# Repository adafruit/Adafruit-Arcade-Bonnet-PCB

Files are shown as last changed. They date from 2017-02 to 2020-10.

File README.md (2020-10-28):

## Adafruit Arcade Bonnet PCB

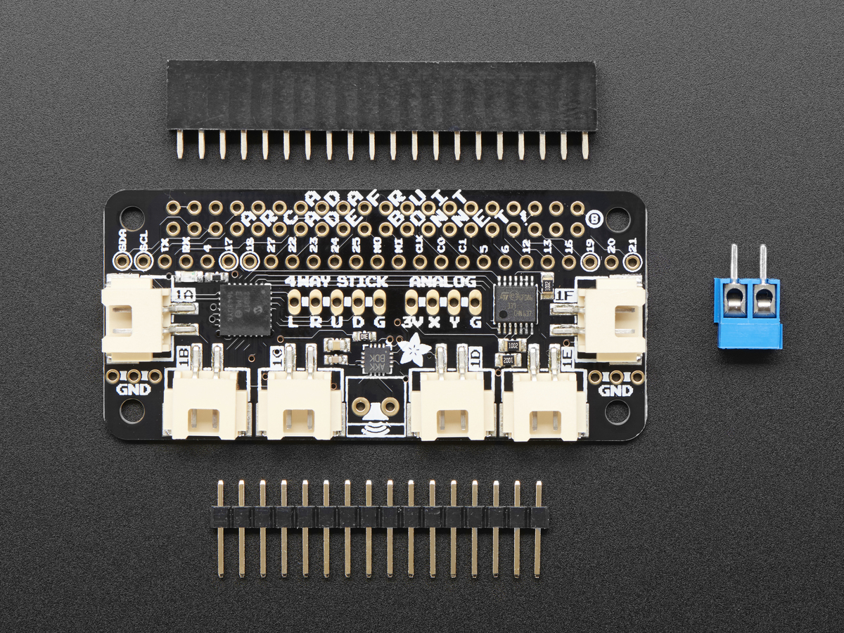
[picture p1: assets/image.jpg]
<a href="http://www.adafruit.com/products/3422"><br/>
Click here to purchase one from the Adafruit shop</a>

PCB files for the Adafruit Arcade Bonnet. Format is EagleCAD schematic and board layout
* http://www.adafruit.com/product/3422

### Description

Playing retro games is easy on a Raspberry Pi - and that pocket-sized computer is pretty good at it too! All you need is a little help to connect buttons and a joystick up and you can custom design your own arcade console, desktop or stand-up machine, even just a simple controller box. It makes for a fun weekend project that will last all year.

This Adafruit Arcade Bonnet is designed to make small emulator projects a little easier to build. Here's what you can look forward to!

* It is the same size as a Pi Zero, so for really compact builds, this is super small. You can also use it with a Pi 2, 3, B+ or any 2x20 connector Pi.
* It has JST sockets so you can plug in six arcade buttons easily using our quick connects.
* Header breakouts for use with both clicky-type switched joysticks and...
* Header breakout and converter for using analog-type joysticks or thumbsticks with potentiometers inside.
* A 3W digital speaker output that can drive 4-8 ohm speakers for when using with a TV output, audio-less HDMI display or PiTFT. Works even when the Pi doesn't have a headphone jack!
* Switches are all managed with an I2C-GPIO converter with interrupt out. The converter is very fast and frees up all the pins so you can use this Bonnet with a PiTFT or any other accessory/device that uses a lot of pins!

If you don't need an amplified speaker output, analog-joystick input or minimal pin usage, check out our plain-jane Retrogame tutorial which just plugs all the buttons and joysticks right into the Pi directly.

This item as sold as a mini-kit, with a Bonnet and headers that need to be soldered in to attach it to a Raspberry Pi! It only takes a few minutes but soldering iron and solder are required.

Note: The terminal block included with your product may be blue or black.

It also does not come with any of the extras, so you can choose which buttons/joysticks/speaker you want! Here is a list of the items you can use:

Joysticks:

* Small Arcade Joystick
* Mini Analog Joystick
* Assembled 2 Axis Joystick
* Analog Thumbstick
* 2 Axis Joystick
* PSP Analog Joystick
* PSP3000 Analog Joystick

To connect them, you may want some 20 x 12" Female jumper wires.

Speakers:

* 4 ohm 3 Watt speaker
* 8 ohm 1 Watt speaker
* Mono enclosed speaker
* Mini Metal speaker (may need to turn the volume down in Emulation station)
* Thin Plastic speaker (may need to turn the volume down in Emulation station)

Arcade Buttons:

* The JST connectors on the Bonnet mate perfectly with Arcade Button Quick-Connect Wire Pairs.
* Any of our Arcade buttons will work. You can use any switch you like, really – doesn't even need to be a button!
* The translucent 30mm ones work nicely with the quick-connects and are recommended!

Note: Raspberry Pi, arcade buttons, joysticks, speaker, display, and quick-connect wires are NOT included, and must be purchased separately.

Once you've picked out all your buttons and joysticks and stuff, check out our [Getting-started guide](https://learn.adafruit.com/adafruit-arcade-bonnet-for-raspberry-pi to help you get going!

### License

Adafruit invests time and resources providing this open source design, please support Adafruit and open-source hardware by purchasing products from [Adafruit](https://www.adafruit.com)!

Designed by Limor Fried/Ladyada for Adafruit Industries.

Creative Commons Attribution/Share-Alike, all text above must be included in any redistribution. See license.txt for additional details.

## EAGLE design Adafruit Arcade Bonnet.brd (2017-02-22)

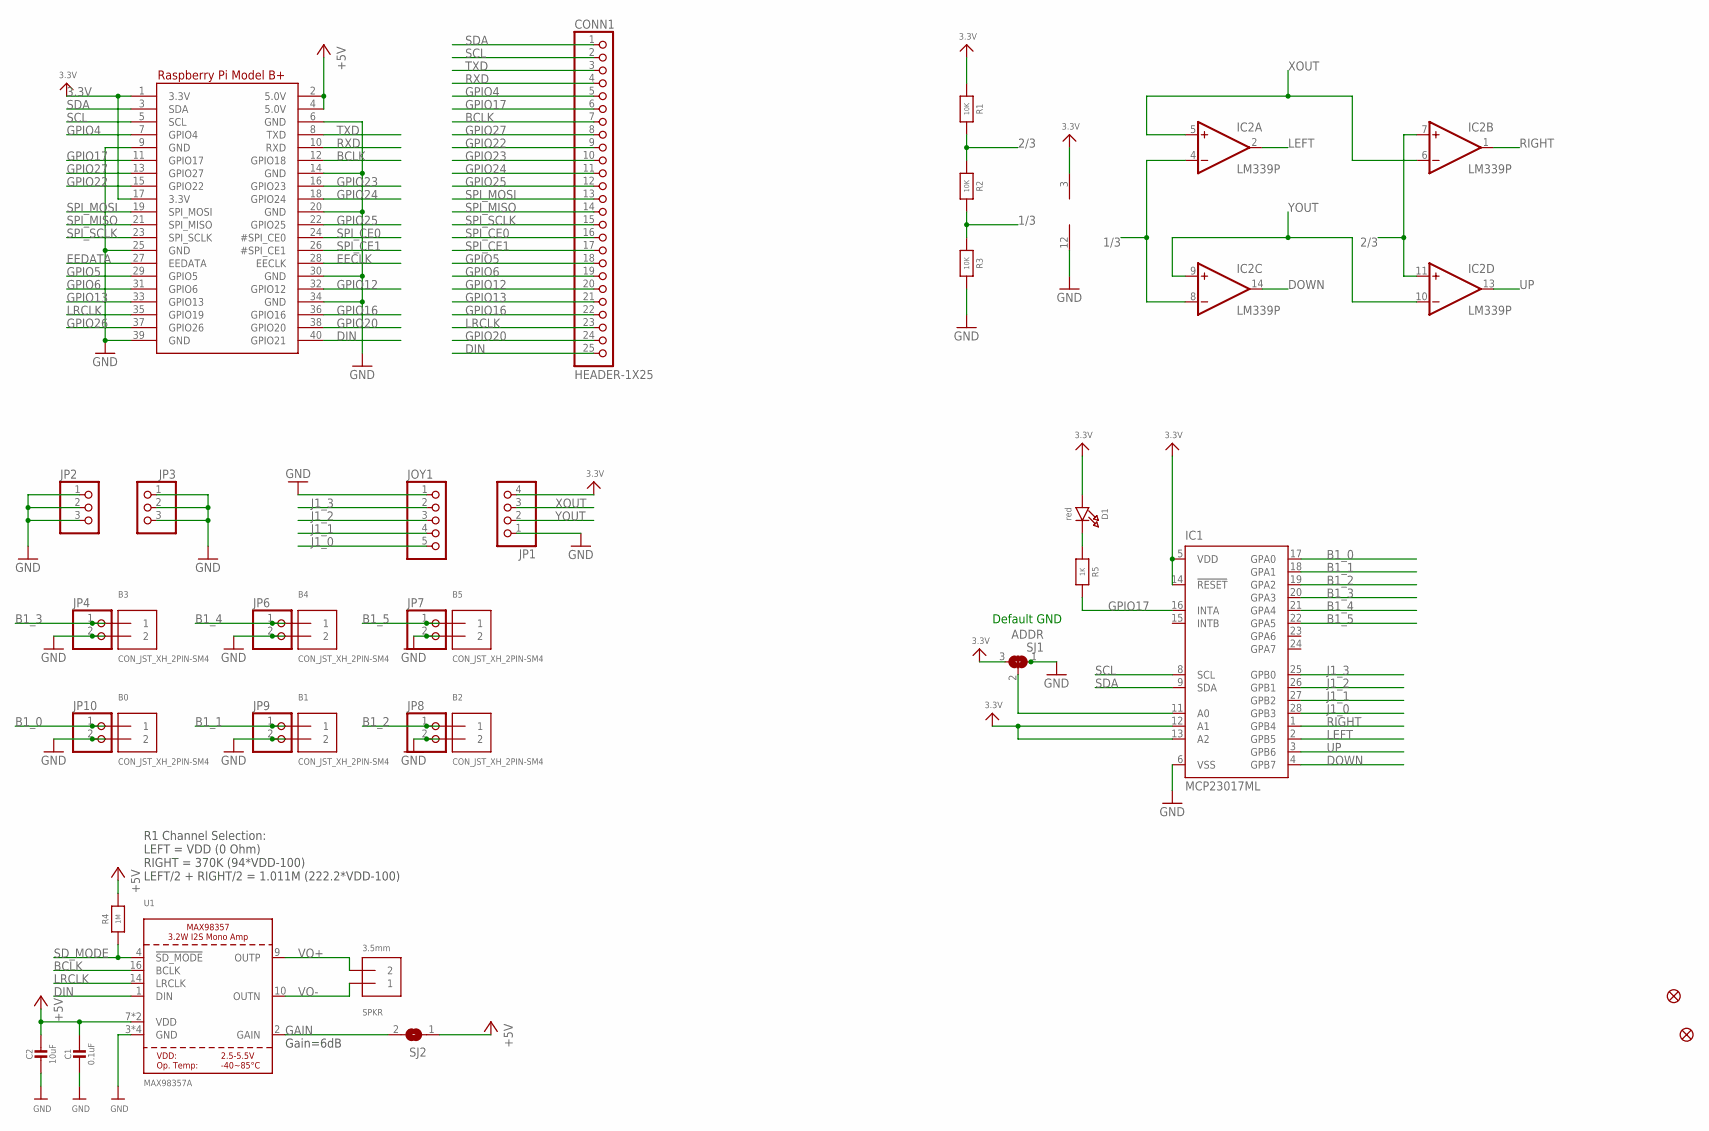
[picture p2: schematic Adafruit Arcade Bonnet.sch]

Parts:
B0, B1, B2, B3, B4, B5: CON_JST_XH_2PIN-SM4; JST-XH-2-SM4
C1: 0.1uF; 0603-NO
C2: 10uF; 0805-NO
CONN1: HEADER-1X25; 1X25_ROUND_70MIL
D1: red; CHIPLED_0805_NOOUTLINE
FID2, FID3: FIDUCIAL""; FIDUCIAL_1MM
IC1: MCP23017ML; QFN28-ML_6X6MM; MPN MCP23017-E/SS
IC2: LM339P; TSSOP14
JOY1: HEADER-1X5; 1X05_OVAL
JP1: HEADER-1X4; 1X04_OVAL
JP2, JP3: HEADER-1X3ROUND; 1X03_ROUND
JP4, JP6, JP7, JP8, JP9, JP10: HEADER-1X2; 1X02_OVAL
R1: 10K; 0805_10MGAP
R2, R3: 10K; 0805-NO
R4: 1M; 0603-NO
R5: 1K; 0603-NO
RPI1: RASPBERRYPI_BPLUS_PHAT; PI_BONNET
SJ1: ADDR; SOLDERJUMPER_2WAY_OPEN_NOPASTE
SJ2: SOLDERJUMPERCLOSED; SOLDERJUMPER_CLOSEDWIRE
SPKR: 3.5mm; TERMBLOCK_1X2-3.5MM
U1: MAX98357A; QFN16_3MM

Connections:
1/3: IC2.4 (-IN), IC2.8 (-IN), R2.2, R3.1
2/3: IC2.7 (+IN), IC2.11 (+IN), R1.2, R2.1
3.3V: D1.A, IC1.5 (VDD), IC1.12 (A1), IC1.13 (A2), IC1.14 (!RESET), IC2.3 (V+), JP1.4, R1.1, RPI1.1 (3.3V), RPI1.17 (3.3V), SJ1.3
+5V: C1.1, C2.1, R4.2, RPI1.2 (5.0V), RPI1.4 (5.0V), SJ2.1, U1.7 (VDD), U1.8 (VDD)
B1_0: B0.1, IC1.17 (GPA0), JP10.1
B1_1: B1.1, IC1.18 (GPA1), JP9.1
B1_2: B2.1, IC1.19 (GPA2), JP8.1
B1_3: B3.1, IC1.20 (GPA3), JP4.1
B1_4: B4.1, IC1.21 (GPA4), JP6.1
B1_5: B5.1, IC1.22 (GPA5), JP7.1
BCLK: CONN1.7, RPI1.12 (GPIO18), U1.16 (BCLK)
DIN: CONN1.25, RPI1.40 (GPIO21), U1.1 (DIN)
DOWN: IC1.4 (GPB7), IC2.14 (OUT)
EECLK: RPI1.28 (EECLK)
EEDATA: RPI1.27 (EEDATA)
GAIN: SJ2.2, U1.2 (GAIN)
GND: B0.2, B1.2, B2.2, B3.2, B4.2, B5.2, C1.2, C2.2, IC1.6 (VSS), IC2.12 (GND), JOY1.1, JP1.1, JP2.1, JP2.2, JP2.3, JP3.1, JP3.2, JP3.3, JP4.2, JP6.2, JP7.2, JP8.2, JP9.2, JP10.2, R3.2, RPI1.6 (GND), RPI1.9 (GND), RPI1.14 (GND), RPI1.20 (GND), RPI1.25 (GND), RPI1.30 (GND), RPI1.34 (GND), RPI1.39 (GND), SJ1.1, U1.3 (GND), U1.11 (GND), U1.15 (GND), U1.THERMAL (GND)
GPIO4: CONN1.5, RPI1.7 (GPIO4)
GPIO5: CONN1.18, RPI1.29 (GPIO5)
GPIO6: CONN1.19, RPI1.31 (GPIO6)
GPIO12: CONN1.20, RPI1.32 (GPIO12)
GPIO13: CONN1.21, RPI1.33 (GPIO13)
GPIO16: CONN1.22, RPI1.36 (GPIO16)
GPIO17: CONN1.6, IC1.16 (INTA), R5.2, RPI1.11 (GPIO17)
GPIO20: CONN1.24, RPI1.38 (GPIO20)
GPIO22: CONN1.9, RPI1.15 (GPIO22)
GPIO23: CONN1.10, RPI1.16 (GPIO23)
GPIO24: CONN1.11, RPI1.18 (GPIO24)
GPIO25: CONN1.12, RPI1.22 (GPIO25)
GPIO26: RPI1.37 (GPIO26)
GPIO27: CONN1.8, RPI1.13 (GPIO27)
J1_0: IC1.28 (GPB3), JOY1.5
J1_1: IC1.27 (GPB2), JOY1.4
J1_2: IC1.26 (GPB1), JOY1.3
J1_3: IC1.25 (GPB0), JOY1.2
LEFT: IC1.2 (GPB5), IC2.2 (OUT)
LRCLK: CONN1.23, RPI1.35 (GPIO19), U1.14 (LRCLK)
unnamed: IC1.11 (A0), SJ1.2
unnamed: D1.C, R5.1
RIGHT: IC1.1 (GPB4), IC2.1 (OUT)
RXD: CONN1.4, RPI1.10 (RXD)
SCL: CONN1.2, IC1.8 (SCL), RPI1.5 (SCL)
SDA: CONN1.1, IC1.9 (SDA), RPI1.3 (SDA)
SD_MODE: R4.1, U1.4 (!SD_MODE)
SPI_CE0: CONN1.16, RPI1.24 (#SPI_CE0)
SPI_CE1: CONN1.17, RPI1.26 (#SPI_CE1)
SPI_MISO: CONN1.14, RPI1.21 (SPI_MISO)
SPI_MOSI: CONN1.13, RPI1.19 (SPI_MOSI)
SPI_SCLK: CONN1.15, RPI1.23 (SPI_SCLK)
TXD: CONN1.3, RPI1.8 (TXD)
UP: IC1.3 (GPB6), IC2.13 (OUT)
VO+: SPKR.2, U1.9 (OUTP)
VO-: SPKR.1, U1.10 (OUTN)
XOUT: IC2.5 (+IN), IC2.6 (-IN), JP1.3
YOUT: IC2.9 (+IN), IC2.10 (-IN), JP1.2

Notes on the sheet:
R1 Channel Selection: LEFT = VDD (0 Ohm) RIGHT = 370K (94*VDD-100) LEFT/2 + RIGHT/2 = 1.011M (222.2*VDD-100)
Gain=6dB
Default GND

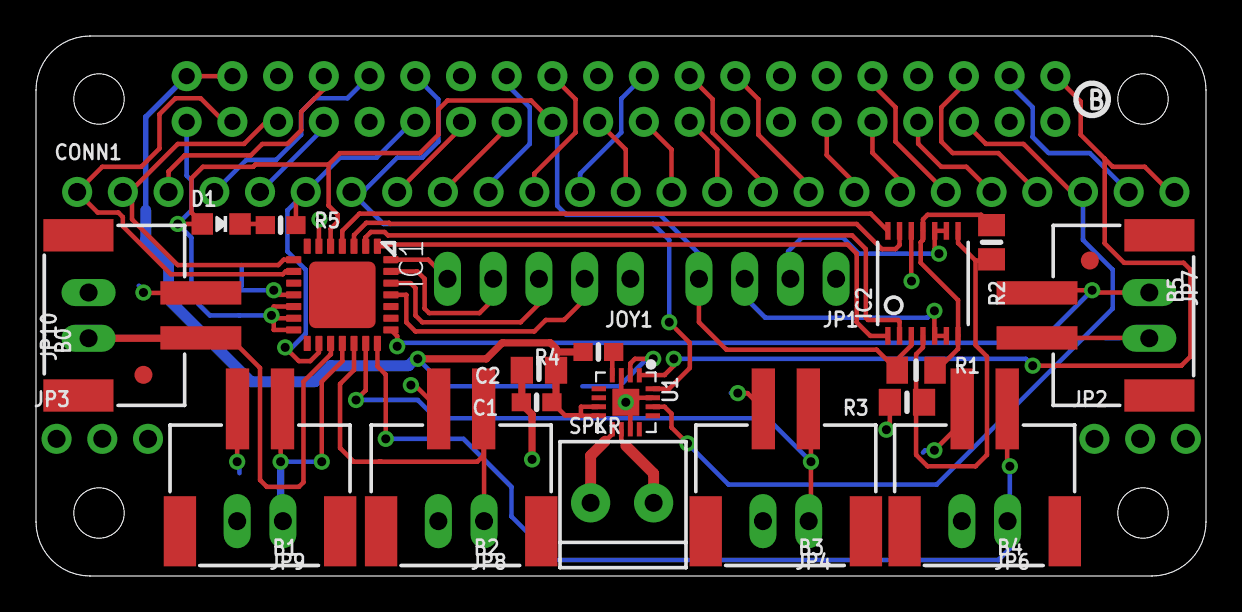
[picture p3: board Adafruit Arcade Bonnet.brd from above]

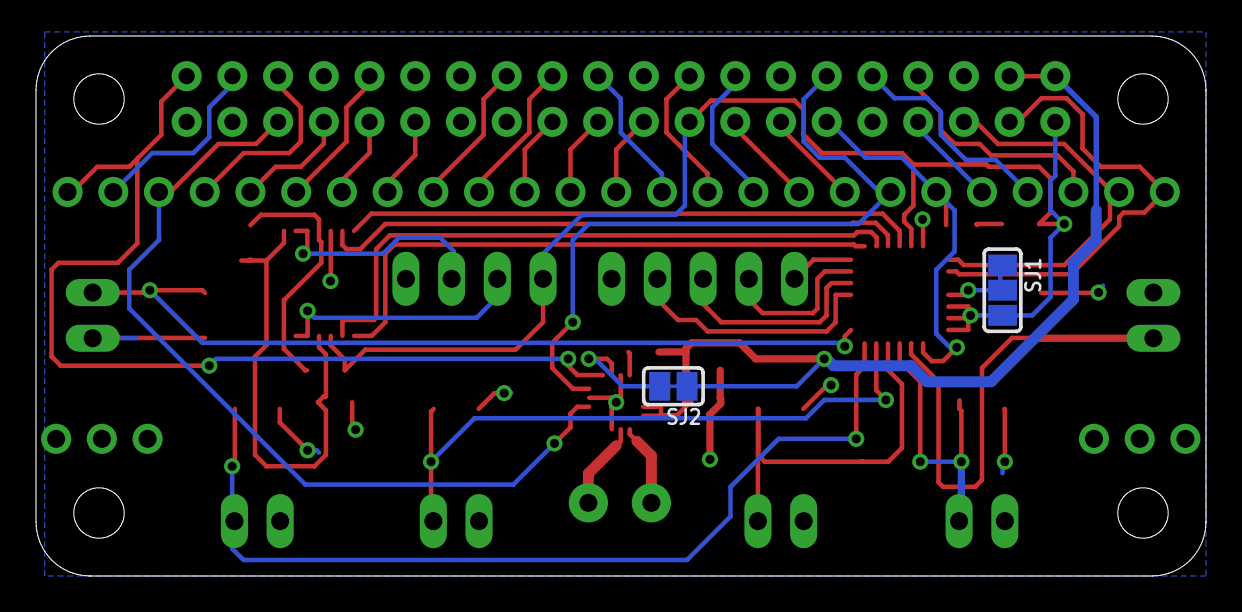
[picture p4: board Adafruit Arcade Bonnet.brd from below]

Board: 2 copper layers, 65.0 x 30.0 mm, 37 parts (3 on the bottom side), 52 nets.

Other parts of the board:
U$11: PCBFEAT-REV-040
U$19: BONNET_ARCADE_REVB_TOP
U$20: BONNET_ARCADE_REVB_BOT

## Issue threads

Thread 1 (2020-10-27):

Incorrect README.md

jdimpson, 2020-10-27:
The README.md file currently in the root of this repo looks like it is meant for another product--one of the temperature and humidity breakouts, I believe. The image and product link seem to be correct.

kattni, 2020-10-28:
Updated README to correct information. Thanks for catching this!

Closed 2020-10-28.

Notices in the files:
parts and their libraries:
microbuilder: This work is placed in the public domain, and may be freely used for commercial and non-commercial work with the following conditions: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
